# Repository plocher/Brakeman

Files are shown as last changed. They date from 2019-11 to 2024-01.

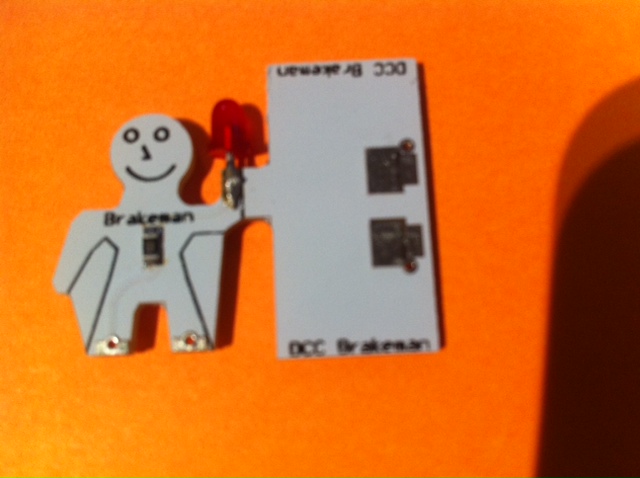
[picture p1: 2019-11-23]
Assembled.jpg

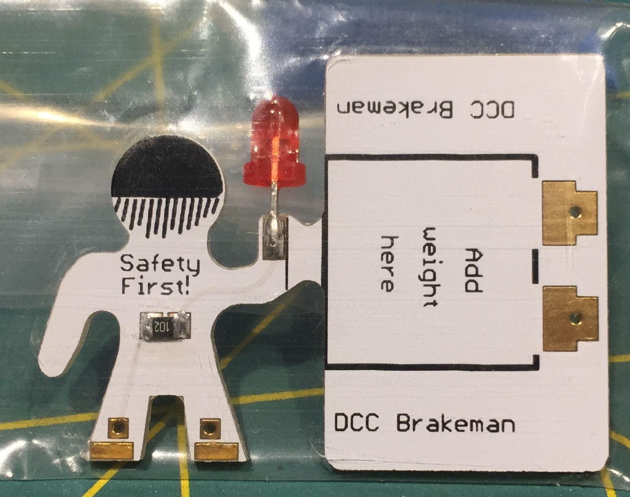
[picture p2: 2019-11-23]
Fabricated-backside.jpg

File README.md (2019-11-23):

# Brakeman
## License: CERN Open Hardware Licence v1.2

An electronic DCC-track-driven figurine with a red or blue LED

## GCOR Rule 6.19 D (paraphrased)
> When a train stops on a main track, flag protection must be provided
> On a layout, torpedoes and fusees are a bit over the top, but a
> brakeman/flagman with a red lantern can add a twist to your next operating
> session.  Adopt prototype practices and have your crews protect
> their trains when switching a town or otherwise fouling the main.
> Just don't forget to recall the flagman before leaving town!

## Designed in the NMRA/PCR for DCC layouts

Assembly required
 
1. V1.0-1.3: Use a track nipper to detach the base from the hand holding the LED.
1. V1.4: Snap the base from the feet and remove any extra PCB frame from around the figure.
1. Solder the two feet to the two small gold pads on the top of the base
1. You can solder a wire (the clipped off resistor leads work well) to strengthen and align this connection
1. Attach the weight to the top of the base next to (but not touching) his feet with double sided foam tape
1. Place the large gold pads across the rails to light the red lantern.

Variation:
  * Make a "Safety Sam" to indicate track or rolling stock that must not be used/moved.  Use 2 BLUE LEDs instead of one RED one - solder them "back to back, opposite" so that one LED's long lead is soldered to the "front" on the raised hand, while the other's long lead is soldered to the figure's "back" on the lowered hand.  Using 2x Blue LEDS is necessary because the Blue LED's have a reverse breakdown voltage close to 5v, while the common Red ones seem to be able to handle 20v+.  (DCC track voltage is ~15v...)

Clean track works best.  Use violates UP Safety Rule 81.2.1, Step Over Rail 

John Plocher, SPCoast.com

> WARNING: This product may contain chemicals known to the State of California to cause cancer and birth defects or other reproductive harm. 

  * Designed for fabrication and ease of assembly

For best results when fab'ing, choose:

  * ENIG (gold) rather than a Hot Air Solder Layer (HASL) for the pads
  * White or Blue soldermask
  * Panalize = 1

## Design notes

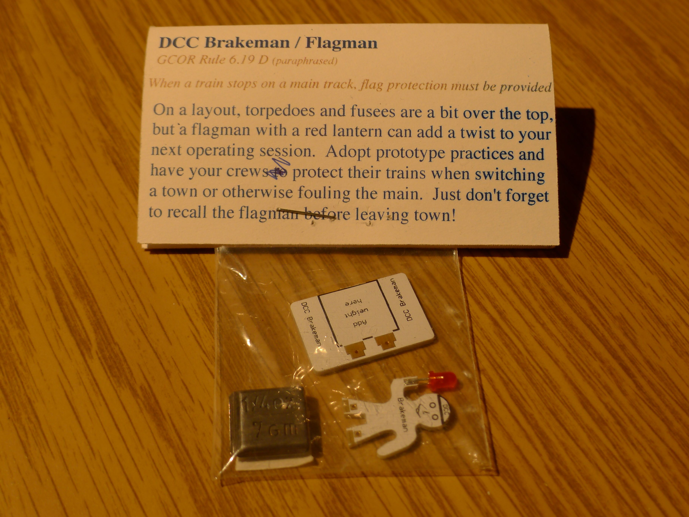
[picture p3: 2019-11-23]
Packaged.jpg

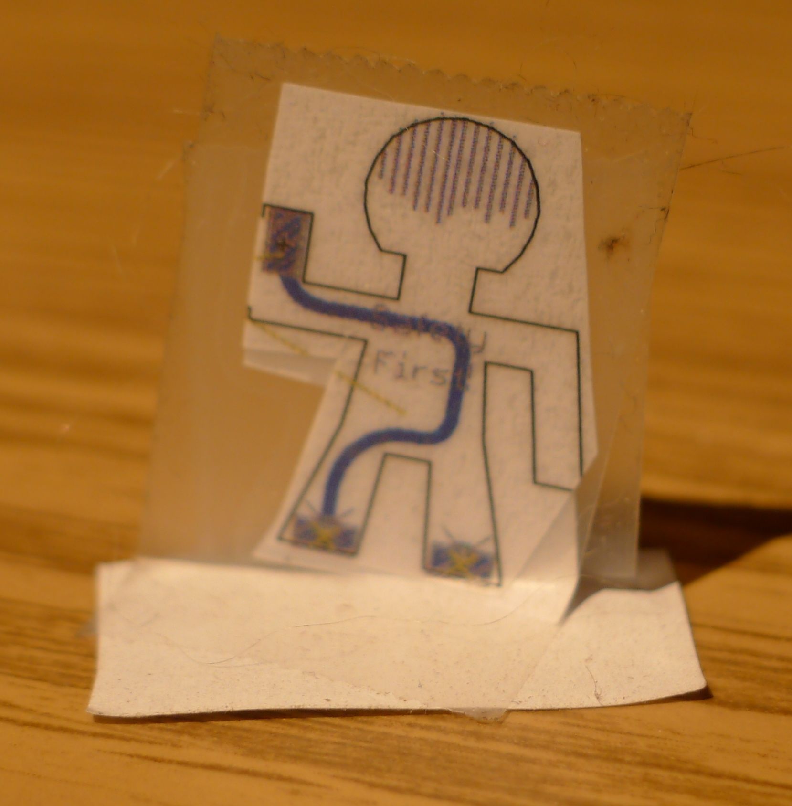
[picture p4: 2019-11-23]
Mockup.jpg

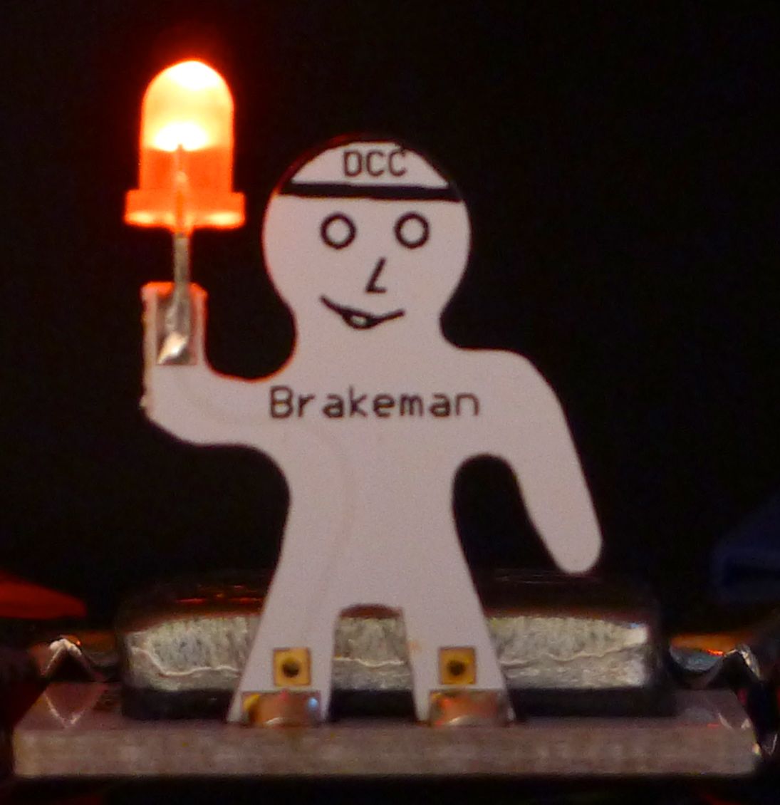
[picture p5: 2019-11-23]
Lit.jpg

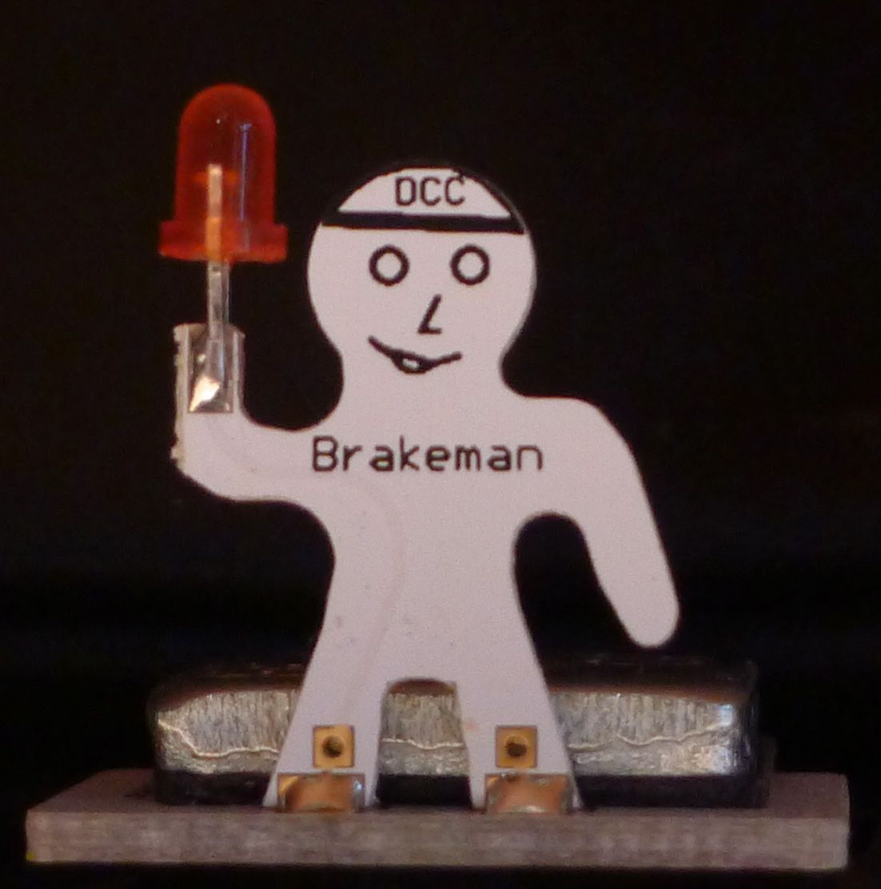
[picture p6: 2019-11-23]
Unlit.jpg

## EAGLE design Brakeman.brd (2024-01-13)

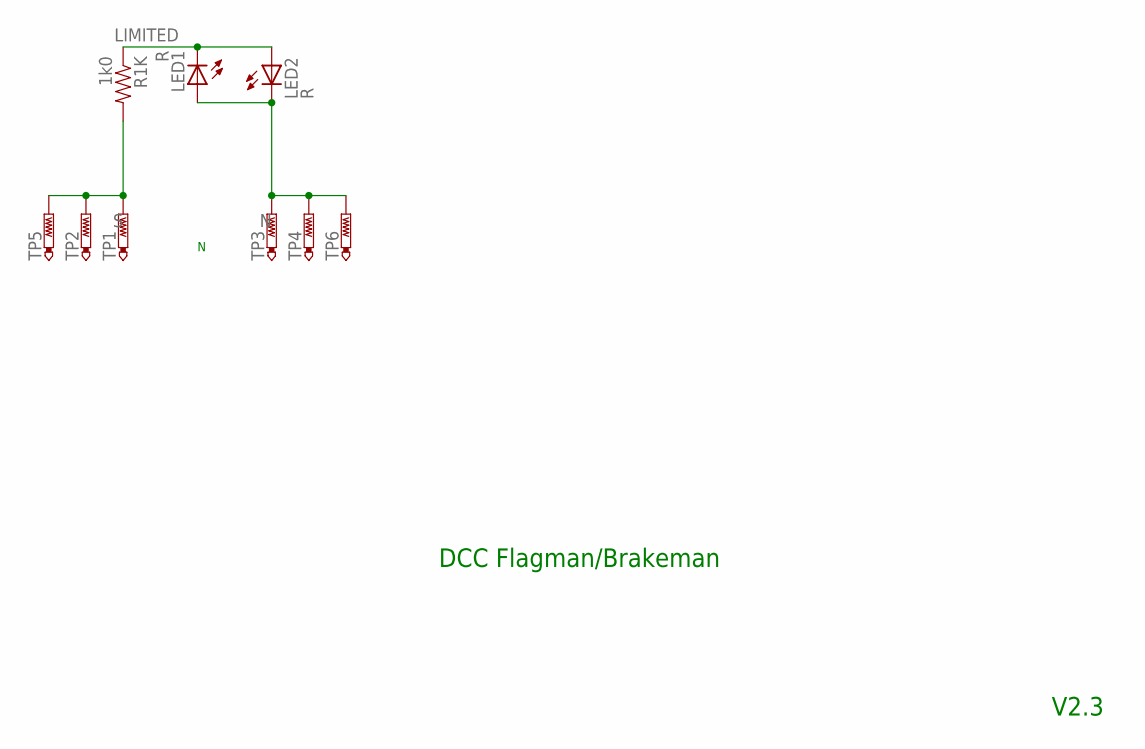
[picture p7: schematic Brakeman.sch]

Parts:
LED1, LED2: R; 0603-LED
R1K: 1k0; 0603-RES
TP1, TP2, TP3, TP4, TP5, TP6: PTR1PAD1-13; P1-13

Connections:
LIMITED: LED1.C, LED2.A, R1K.1
N: LED1.A, LED2.C, TP3.TP, TP4.TP, TP6.TP
S: R1K.2, TP1.TP, TP2.TP, TP5.TP

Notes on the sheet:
DCC Flagman/Brakeman
V2.3

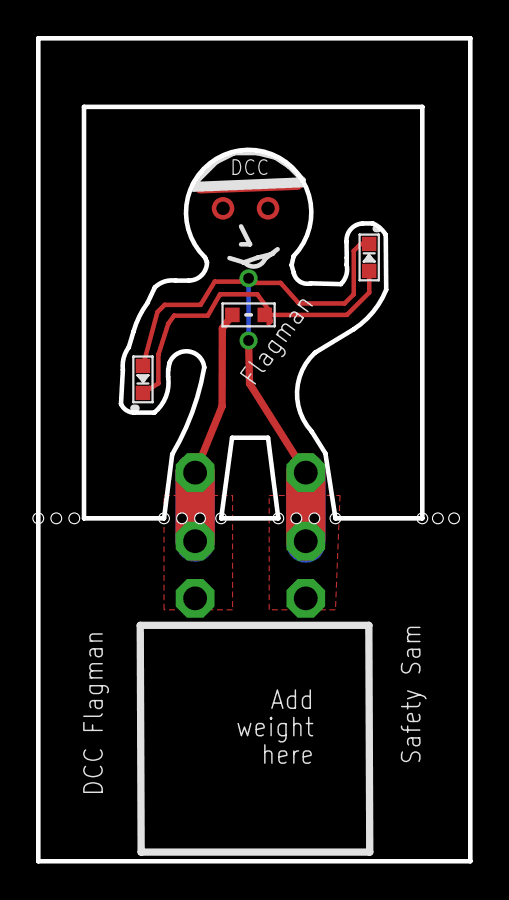
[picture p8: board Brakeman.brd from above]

Board: 2 copper layers, 24.0 x 45.7 mm, 9 parts (0 on the bottom side), 3 nets.

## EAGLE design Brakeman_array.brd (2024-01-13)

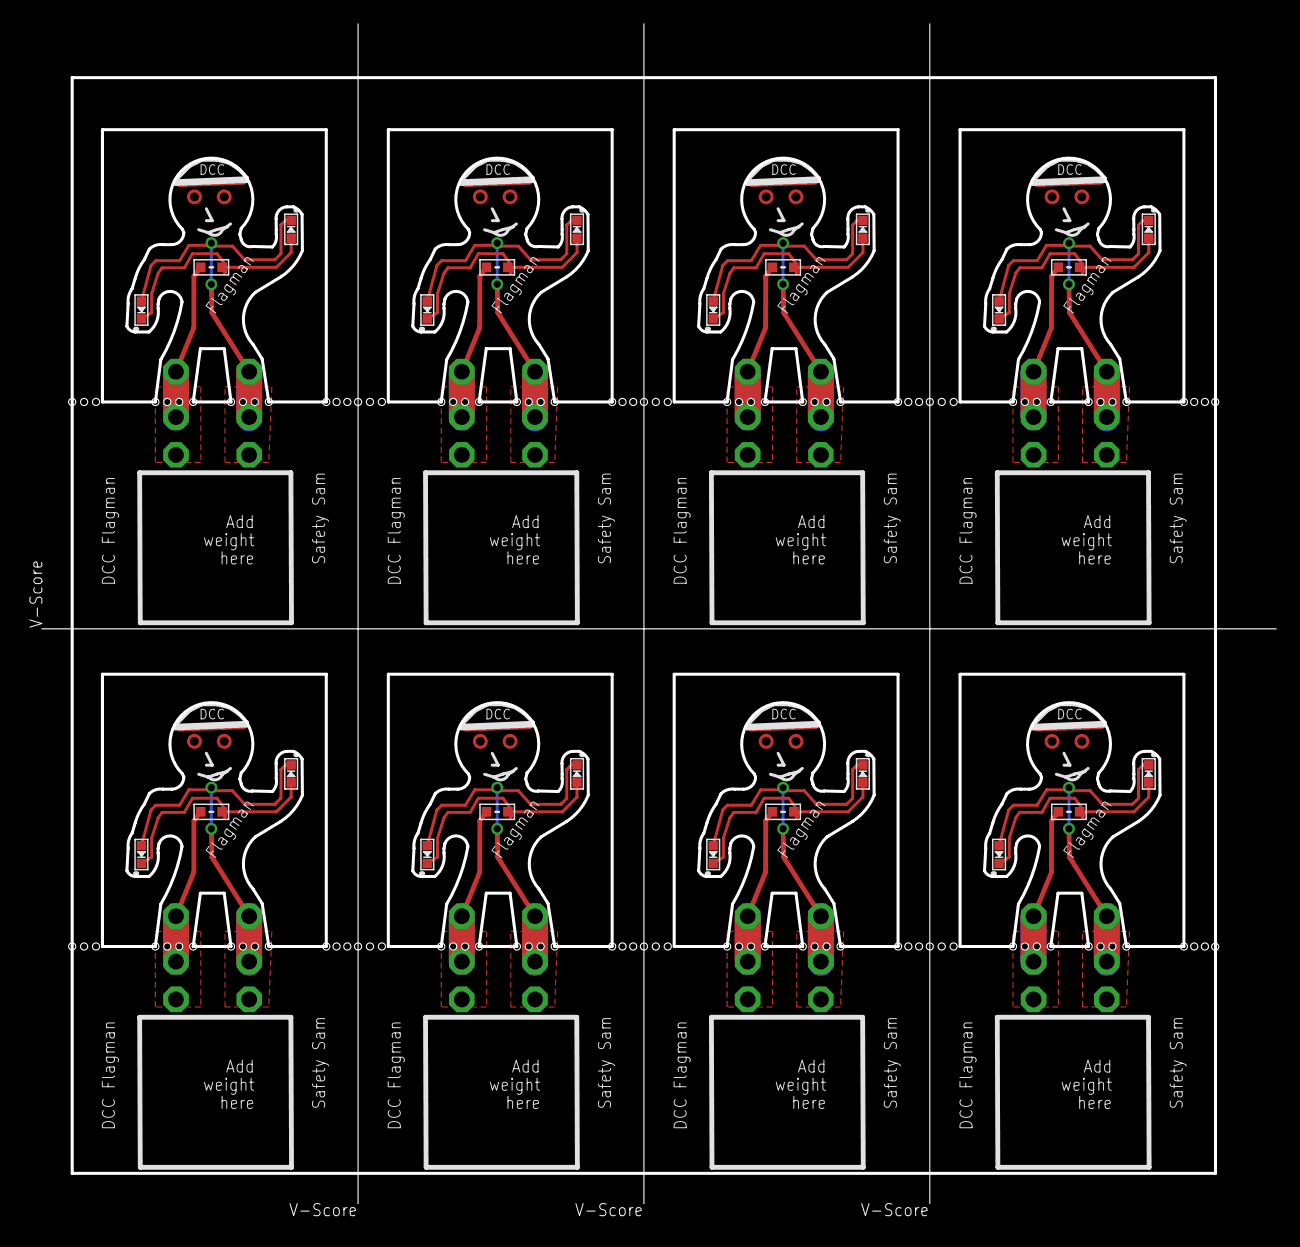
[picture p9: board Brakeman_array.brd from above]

Board: 2 copper layers, 103.6 x 99.1 mm, 72 parts (0 on the bottom side), 24 nets.

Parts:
LED1X11, LED1X12, LED1X21, LED1X22, LED1X31, LED1X32, LED1X41, LED1X42, LED2X11, LED2X12, LED2X21, LED2X22, LED2X31, LED2X32, LED2X41, LED2X42: R; 0603-LED
R1KX11, R1KX12, R1KX21, R1KX22, R1KX31, R1KX32, R1KX41, R1KX42: 1k0; 0603-RES
TP1X11, TP1X12, TP1X21, TP1X22, TP1X31, TP1X32, TP1X41, TP1X42, TP2X11, TP2X12, TP2X21, TP2X22, TP2X31, TP2X32, TP2X41, TP2X42, TP3X11, TP3X12, TP3X21, TP3X22, TP3X31, TP3X32, TP3X41, TP3X42, TP4X11, TP4X12, TP4X21, TP4X22, TP4X31, TP4X32, TP4X41, TP4X42, TP5X11, TP5X12, TP5X21, TP5X22, TP5X31, TP5X32, TP5X41, TP5X42, TP6X11, TP6X12, TP6X21, TP6X22, TP6X31, TP6X32, TP6X41, TP6X42: PTR1PAD1-13; P1-13

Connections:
LIMITEDX11: LED1X11.C, LED2X11.A, R1KX11.1
LIMITEDX12: LED1X12.C, LED2X12.A, R1KX12.1
LIMITEDX21: LED1X21.C, LED2X21.A, R1KX21.1
LIMITEDX22: LED1X22.C, LED2X22.A, R1KX22.1
LIMITEDX31: LED1X31.C, LED2X31.A, R1KX31.1
LIMITEDX32: LED1X32.C, LED2X32.A, R1KX32.1
LIMITEDX41: LED1X41.C, LED2X41.A, R1KX41.1
LIMITEDX42: LED1X42.C, LED2X42.A, R1KX42.1
NX11: LED1X11.A, LED2X11.C, TP3X11.TP, TP4X11.TP, TP6X11.TP
NX12: LED1X12.A, LED2X12.C, TP3X12.TP, TP4X12.TP, TP6X12.TP
NX21: LED1X21.A, LED2X21.C, TP3X21.TP, TP4X21.TP, TP6X21.TP
NX22: LED1X22.A, LED2X22.C, TP3X22.TP, TP4X22.TP, TP6X22.TP
NX31: LED1X31.A, LED2X31.C, TP3X31.TP, TP4X31.TP, TP6X31.TP
NX32: LED1X32.A, LED2X32.C, TP3X32.TP, TP4X32.TP, TP6X32.TP
NX41: LED1X41.A, LED2X41.C, TP3X41.TP, TP4X41.TP, TP6X41.TP
NX42: LED1X42.A, LED2X42.C, TP3X42.TP, TP4X42.TP, TP6X42.TP
SX11: R1KX11.2, TP1X11.TP, TP2X11.TP, TP5X11.TP
SX12: R1KX12.2, TP1X12.TP, TP2X12.TP, TP5X12.TP
SX21: R1KX21.2, TP1X21.TP, TP2X21.TP, TP5X21.TP
SX22: R1KX22.2, TP1X22.TP, TP2X22.TP, TP5X22.TP
SX31: R1KX31.2, TP1X31.TP, TP2X31.TP, TP5X31.TP
SX32: R1KX32.2, TP1X32.TP, TP2X32.TP, TP5X32.TP
SX41: R1KX41.2, TP1X41.TP, TP2X41.TP, TP5X41.TP
SX42: R1KX42.2, TP1X42.TP, TP2X42.TP, TP5X42.TP

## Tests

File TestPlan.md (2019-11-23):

## Brakeman Testplan and Assembly:

-   SMT 1K0 0805 or PTH resistor on body top surface
-   Cut the LED leads to between 3mm and 4mm long
-   Edge mount the Red LED to the raised arm, polarity does not matter
    -   Colors other than red: must use 2x LEDS, one on each arm, with
        opposite polarity

Testing:

-   Red LED:
    -   Touch 9-12vAC to one \"foot\" and Gnd to the other,
    -   observe RED LED on hand light up.
-   Other Colors:
    -   Touch 9-12vDC to one foot and GND the other,
    -   Observe ONE LED light up
    -   Reverse the foot connections
    -   Observe the OTHER LED light up

The end user will snap apart the base and body, solder the feet to the
base and attach a lead weight to the base, making a figure with a LED
lantern in its hand that lights up when placed on a HO model railroad
track.

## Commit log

2020-10-05 added values for connectors
    [Brakeman.brd, Brakeman.sch, Brakeman_array.brd]
2024-01-12 Version 2.4
    [Brakeman.GBL, Brakeman.GBO, Brakeman.GBP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]
2024-01-12 Revert "Version 2.4"
    This reverts commit de817f9b6bc09cb4258c25781ce6263bd1cc7bce.
    [Brakeman.GBL, Brakeman.GBO, Brakeman.GBP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]
2024-01-12 smt and 2x LEDs
2024-01-13 Version 2.5
    [Brakeman.sch]
2024-01-13 added foot tiedowns
    [Brakeman.brd, Brakeman.sch, Brakeman_array.brd]
